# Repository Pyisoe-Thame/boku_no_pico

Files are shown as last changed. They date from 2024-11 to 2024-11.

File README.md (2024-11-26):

# Boku no Pico

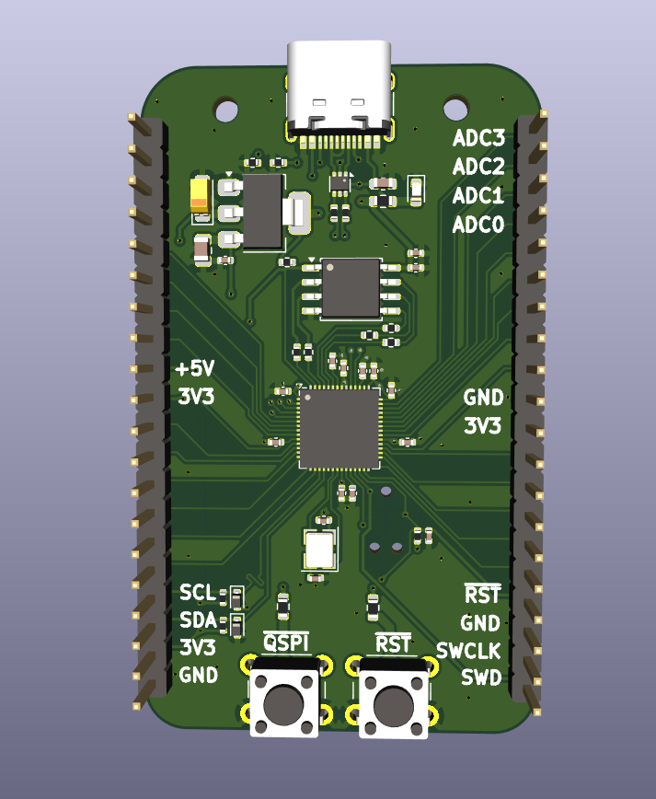
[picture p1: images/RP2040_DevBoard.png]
Front View

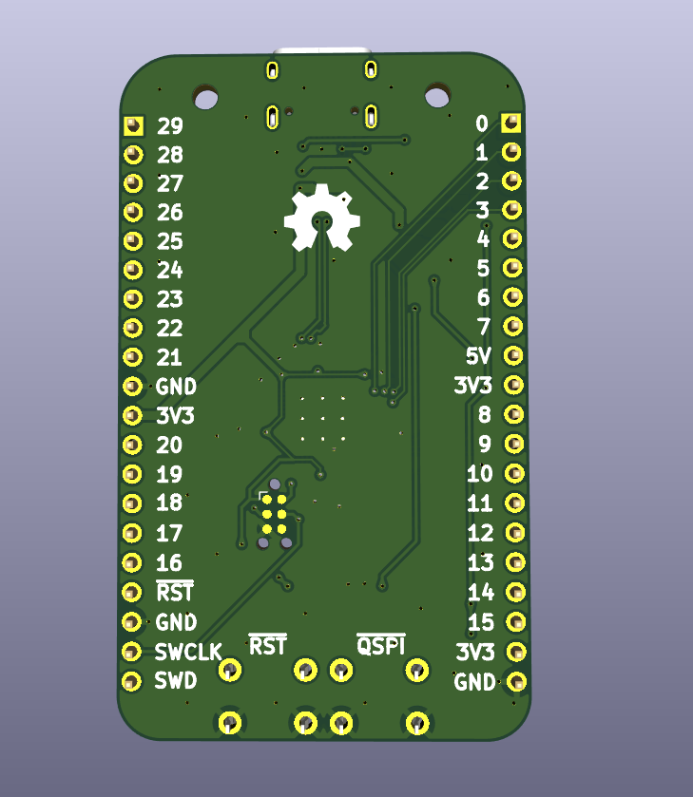
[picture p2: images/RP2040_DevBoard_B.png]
Back View
 

## Introduction
This repository contains the design files and documentation for Boku no Pico (RP2040) development board, which is a variant of ARM Cortex-M0+ Raspberry Pi Pico. This board is tailored to enhance development for embedded systems enthusiasts by adding essential features and simplifying debugging and prototyping.

---

## Features
- Powered by the Raspberry Pi RP2040 microcontroller.
- Standard 4-pin SWD and I2C headers 
- USB-C connector for modern connectivity.
- Application of robustment enhancing techniques.
- Compact, breadboard-friendly form factor.

---

## Schematic and PCB Design
The hardware design was created using **KiCad**. The following files are included:
- **Schematic**: `RP2040_DevBoard.kicad_sch`
- **PCB layout**: `RP2040_DevBoard.kicad_pcb`

### Folder Structure
- `BOM/`: Bill of Materials for the components used.
- `PCB/`: Gerber files, Drill files and PaP files.
- `images/`: Board images in 3D but no rendered.

---

## How to Use
### Hardware Setup
1. Assembly the PCB by handing the files inside BOM and PCB folders to a PCB manufacturer such as PCBHero or JLCPCB.
2. Hand-solder manually the pin headers or the way you want (e.g. sockets, wires)
3. Use a 4-pin SWD debugger (e.g., J-Link or Picoprobe) or Arm connector tag for flashing firmware.

### Programming
- Use the official Raspberry Pi Pico SDK for development.
- Alternatively, program using MicroPython or CircuitPython.

---

## Getting Started
1. Clone this repository:
   ```bash
   git clone https://github.com/Pyisoe-Thame/boku_no_pico.git

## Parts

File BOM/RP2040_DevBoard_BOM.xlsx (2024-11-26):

Designator | Label | LCSC Part # | Mfr. Part # | Manufacturer | Footprint | Quantity | Price | Stock Minimum | Cost | Actual Cost | 5 Boards Cost
C1, C4, C5, C6, C9, 10, C11, C12, C13, C15, C19 | 100nF | C392963 | TCC0402X7R104K160AT | CCTC | C_0402_1005Metric | 11 | $0.0009 | 100 | $0.0099 | $0.0900 | $0.0495
C7, C8 | 220nF | C7503518 | CGA0402X5R224K100GT | HRE | C_0402_1005Metric | 2 | 0.0014 | 100 | $0.0028 | $0.1400 | $0.0140
C2, C3 | 22pF | C2175872 | CC0402JRNPO7BN220 | YAGEO | C_0402_1005Metric | 2 | $0.0011 | 100 | $0.0022 | $0.1100 | $0.0110
C18 | 1uF | C5142580 | TCC0402X5R105K160AT | CCTC | C_0402_1005Metric | 1 | $0.0020 | 100 | $0.0020 | $0.2000 | $0.0100
C14 | 4.7uF | C6119855 | CGA0603X5R475K160JT | HRE | C_0603_1608Metric | 1 | $0.0058 | 100 | $0.0058 | $0.5800 | $0.0290
C16 | 10uF | C1713 | CL21A106KOQNNNE | Samsung Electro-Mechanics | C_0805_2012Metric | 1 | $0.0078 | 20 | $0.0078 | $0.1560 | $0.0390
C17 | 22uF | C124838 | TC212A226M010B | Sunlord | CP_EIA-3216-18_Kemet-A | 1 | $0.0928 | 5 | $0.0928 | $0.4640 | $0.4640
D1, D2 | ESD5Z3.3C | C5180227 | ESD5Z3.3C-ES | ElecSuper | D_SOD-523 | 2 | $0.0132 | 5 | $0.0264 | $0.0660 | $0.1320
D3 | Red | C965799 | XL-1608SURC-06 | XINGLIGHT | LED_0603_1608Metric | 1 | $0.0030 | 100 | $0.0030 | $0.3000 | $0.0150
J1 | USB_C_2.0 | C165948 | TYPE-C-31-M-12 | Korean Hroparts Elec | USB_C_Receptacle_HRO_TYPE-C-31-M-12 | 1 | $0.1552 | 5 | $0.1552 | $0.7760 | $0.7760
R1, R11, R14, R15 | 10k | C3017497 | SCR0402J10K | VO | R_0402_1005Metric | 2 | $0.0004 | 100 | $0.0008 | $0.0400 | $0.0040
R2, R3, R4, R5, R6, R7, R8 | 27R | C2929914 | FRC0402J270TS | FOJAN | R_0402_1005Metric | 7 | $0.0003 | 100 | $0.0021 | $0.0300 | $0.0105
R9, R10 | 5k1 | C23186 | 0603WAF5101T5E | UNI-ROYAL(Uniroyal Elec) | R_0402_1005Metric | 2 | $0.0010 | 100 | $0.0020 | $0.1000 | $0.0100
R12, R13 | 1k | C881173 | CR0603J1K00P05Z | Ever Ohms Tech | R_0603_1608Metric | 2 | $0.0013 | 100 | $0.0026 | $0.1300 | $0.0130
R16 | 220R | C22962 | 0603WAF2200T5E | UNI-ROYAL(Uniroyal Elec) | R_0603_1608Metric | 1 | $0.0010 | 100 | $0.0010 | $0.1000 | $0.0050
SW1, SW2 | SW_Push | C29781309 | SMG-01-H055A1 | SM Switch | SW_PUSH_6mm | 2 | $0.0154 | 20 | $0.0308 | $0.3080 | $0.1540
U1 | RP2040 | C2040 | RP2040 | Raspberry Pi | QFN-56-1EP_7x7mm_P0.4mm_EP4x4mm_ThermalVias | 1 | $1.0357 | 1 | $1.0357 | $1.0357 | $5.1785
U2 | USBLC6-2P6 | C19188420 | LM-USBLC6-2P6 | Leiditech | SOT-563 | 1 | $0.0516 | 5 | $0.0516 | $0.2580 | $0.2580
U3 | AMS1117-3.3 | C347222 | AMS1117-3.3 | UMW(Youtai Semiconductor Co., Ltd.) | SOT-223-3_TabPin2 | 1 | $0.0335 | 5 | $0.0335 | $0.1675 | $0.1675
U4 | W25Q16JVSS | C82317 | W25Q16JVSSIQ | Winbond Elec | SOIC-8_5.275x5.275mm_P1.27mm | 1 | $0.2263 | 5 | $0.2263 | $1.1315 | $1.1315
Y1 | ABM8-272-T3 | C20625731 | ABM8-272-T3 | Abracon LLC | Crystal_SMD_Abracon_ABM8G-4Pin_3.2x2.5mm | 1 | $0.4899 | 1 | $0.4899 | $0.4899 | $2.4495
Total |  |  |  |  |  |  |  |  | $2.1842 | $6.6726 | $10.9210
 |  | Note: pin headers excluded

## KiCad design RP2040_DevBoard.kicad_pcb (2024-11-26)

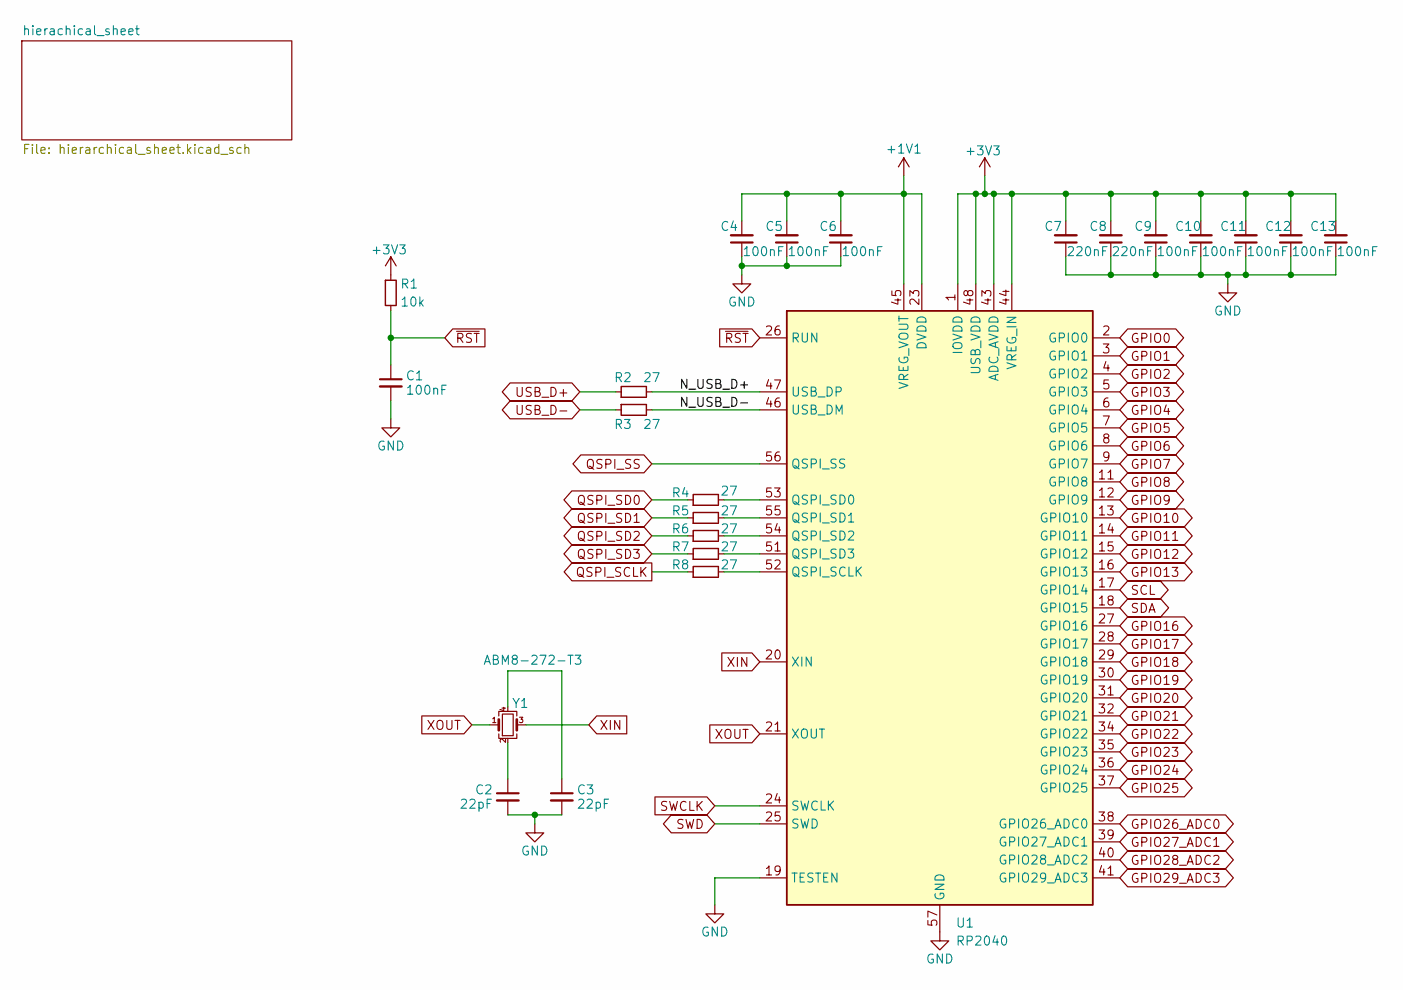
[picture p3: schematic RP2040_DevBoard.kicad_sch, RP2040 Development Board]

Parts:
C1, C4, C5, C6, C9, C10, C11, C12, C13: 100nF; C_0402_1005Metric
C2, C3: 22pF; C_0402_1005Metric
C7, C8: 220nF; C_0402_1005Metric
R1: 10k; R_0402_1005Metric
R2, R3, R4, R5, R6, R7, R8: 27; R_0402_1005Metric
U1: RP2040; QFN-56-1EP_7x7mm_P0.4mm_EP4x4mm
Y1: ABM8-272-T3; Crystal_SMD_Abracon_ABM8G-4Pin_3.2x2.5mm

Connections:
+1V1: C4.2, C5.2, C6.2, U1.23 (DVDD), U1.45 (VREG_VOUT), U1.50 (DVDD)
+3V3: C7.2, C8.2, C9.2, C10.2, C11.2, C12.2, C13.2, R1.1, U1.1 (IOVDD), U1.10 (IOVDD), U1.22 (IOVDD), U1.33 (IOVDD), U1.42 (IOVDD), U1.43 (ADC_AVDD), U1.44 (VREG_IN), U1.48 (USB_VDD), U1.49 (IOVDD); also elsewhere on the board
/N_USB_D+: R2.2, U1.47 (USB_DP)
/N_USB_D-: R3.2, U1.46 (USB_DM)
GND: C1.2, C2.2, C3.2, C4.1, C5.1, C6.1, C7.1, C8.1, C9.1, C10.1, C11.1, C12.1, C13.1, U1.19 (TESTEN), U1.57 (GND); also elsewhere on the board
GPIO0: U1.2 (GPIO0); also elsewhere on the board
GPIO1: U1.3 (GPIO1); also elsewhere on the board
GPIO2: U1.4 (GPIO2); also elsewhere on the board
GPIO3: U1.5 (GPIO3); also elsewhere on the board
GPIO4: U1.6 (GPIO4); also elsewhere on the board
GPIO5: U1.7 (GPIO5); also elsewhere on the board
GPIO6: U1.8 (GPIO6); also elsewhere on the board
GPIO7: U1.9 (GPIO7); also elsewhere on the board
GPIO8: U1.11 (GPIO8); also elsewhere on the board
GPIO9: U1.12 (GPIO9); also elsewhere on the board
GPIO10: U1.13 (GPIO10); also elsewhere on the board
GPIO11: U1.14 (GPIO11); also elsewhere on the board
GPIO12: U1.15 (GPIO12); also elsewhere on the board
GPIO13: U1.16 (GPIO13); also elsewhere on the board
GPIO16: U1.27 (GPIO16); also elsewhere on the board
GPIO17: U1.28 (GPIO17); also elsewhere on the board
GPIO18: U1.29 (GPIO18); also elsewhere on the board
GPIO19: U1.30 (GPIO19); also elsewhere on the board
GPIO20: U1.31 (GPIO20); also elsewhere on the board
GPIO21: U1.32 (GPIO21); also elsewhere on the board
GPIO22: U1.34 (GPIO22); also elsewhere on the board
GPIO23: U1.35 (GPIO23); also elsewhere on the board
GPIO24: U1.36 (GPIO24); also elsewhere on the board
GPIO25: U1.37 (GPIO25); also elsewhere on the board
GPIO26_ADC0: U1.38 (GPIO26_ADC0); also elsewhere on the board
GPIO27_ADC1: U1.39 (GPIO27_ADC1); also elsewhere on the board
GPIO28_ADC2: U1.40 (GPIO28_ADC2); also elsewhere on the board
GPIO29_ADC3: U1.41 (GPIO29_ADC3); also elsewhere on the board
unnamed: C2.1, Y1.2
unnamed: C3.1, Y1.4
unnamed: R8.2, U1.52 (QSPI_SCLK)
unnamed: R4.2, U1.53 (QSPI_SD0)
unnamed: R5.2, U1.55 (QSPI_SD1)
unnamed: R6.2, U1.54 (QSPI_SD2)
unnamed: R7.2, U1.51 (QSPI_SD3)
QSPI_SCLK: R8.1; also elsewhere on the board
QSPI_SD0: R4.1; also elsewhere on the board
QSPI_SD1: R5.1; also elsewhere on the board
QSPI_SD2: R6.1; also elsewhere on the board
QSPI_SD3: R7.1; also elsewhere on the board
QSPI_SS: U1.56 (QSPI_SS); also elsewhere on the board
SCL: U1.17 (GPIO14); also elsewhere on the board
SDA: U1.18 (GPIO15); also elsewhere on the board
SWCLK: U1.24 (SWCLK); also elsewhere on the board
SWD: U1.25 (SWD); also elsewhere on the board
USB_D+: R2.1; also elsewhere on the board
USB_D-: R3.1; also elsewhere on the board
XIN: U1.20 (XIN), Y1.3
XOUT: U1.21 (XOUT), Y1.1
~RST: C1.1, R1.2, U1.26 (RUN); also elsewhere on the board

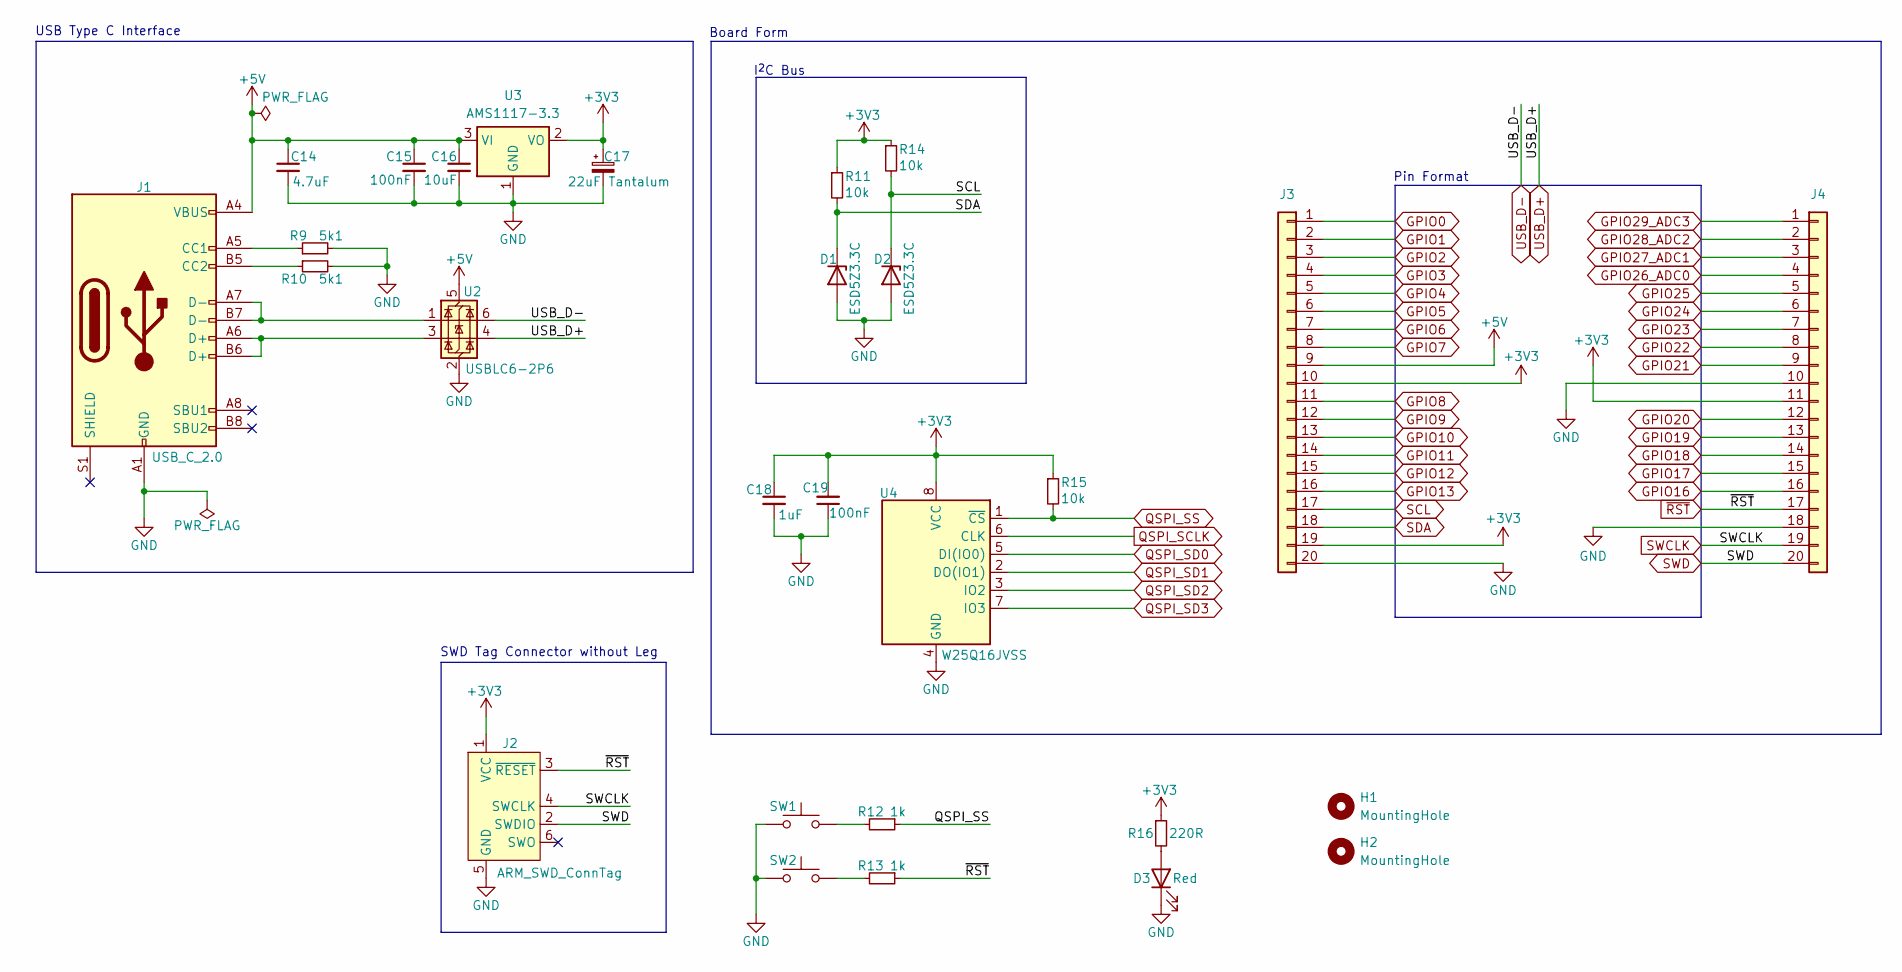
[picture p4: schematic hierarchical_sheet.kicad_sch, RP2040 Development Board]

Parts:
C14: 4.7uF; C_0603_1608Metric
C15, C19: 100nF; C_0402_1005Metric
C16: 10uF; C_0805_2012Metric
C17: 22uF; CP_EIA-3216-18_Kemet-A
C18: 1uF; C_0402_1005Metric
D1, D2: ESD5Z3.3C; D_SOD-523
D3: Red; LED_0603_1608Metric
H1, H2: MountingHole; MountingHole_2.2mm_M2
J1: USB_C_2.0; USB_C_Receptacle_HRO_TYPE-C-31-M-12
J2: ARM_SWD_ConnTag; Tag-Connect_TC2030-IDC-NL_2x03_P1.27mm_Vertical
J3, J4: Conn_01x20; PinHeader_1x20_P2.54mm_Vertical
R9, R10: 5k1; R_0402_1005Metric
R11, R14, R15: 10k; R_0402_1005Metric
R12, R13: 1k; R_0603_1608Metric
R16: 220R; R_0603_1608Metric
SW1, SW2: SW_Push; SW_PUSH_6mm
U2: USBLC6-2P6; SOT-563
U3: AMS1117-3.3; SOT-223-3_TabPin2
U4: W25Q16JVSS; SOIC-8_5.275x5.275mm_P1.27mm

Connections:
+3V3: C17.1, C18.1, C19.2, J2.1 (VCC), J3.10, J3.19, J4.11, R11.1, R14.1, R15.1, R16.1, U3.2 (VO), U4.8 (VCC); also elsewhere on the board
+5V: C14.1, C15.1, C16.1, J1.A4 (VBUS), J1.A9 (VBUS), J1.B4 (VBUS), J1.B9 (VBUS), J3.9, U2.5 (VBUS), U3.3 (VI)
GND: C14.2, C15.2, C16.2, C17.2, C18.2, C19.1, D1.2 (A), D2.2 (A), D3.1 (K), J1.A1 (GND), J1.A12 (GND), J1.B1 (GND), J1.B12 (GND), J2.5 (GND), J3.20, J4.10, J4.18, R9.2, R10.2, SW1.1, SW2.1, U2.2 (GND), U3.1 (GND), U4.4 (GND); also elsewhere on the board
GPIO0: J3.1; also elsewhere on the board
GPIO1: J3.2; also elsewhere on the board
GPIO2: J3.3; also elsewhere on the board
GPIO3: J3.4; also elsewhere on the board
GPIO4: J3.5; also elsewhere on the board
GPIO5: J3.6; also elsewhere on the board
GPIO6: J3.7; also elsewhere on the board
GPIO7: J3.8; also elsewhere on the board
GPIO8: J3.11; also elsewhere on the board
GPIO9: J3.12; also elsewhere on the board
GPIO10: J3.13; also elsewhere on the board
GPIO11: J3.14; also elsewhere on the board
GPIO12: J3.15; also elsewhere on the board
GPIO13: J3.16; also elsewhere on the board
GPIO16: J4.16; also elsewhere on the board
GPIO17: J4.15; also elsewhere on the board
GPIO18: J4.14; also elsewhere on the board
GPIO19: J4.13; also elsewhere on the board
GPIO20: J4.12; also elsewhere on the board
GPIO21: J4.9; also elsewhere on the board
GPIO22: J4.8; also elsewhere on the board
GPIO23: J4.7; also elsewhere on the board
GPIO24: J4.6; also elsewhere on the board
GPIO25: J4.5; also elsewhere on the board
GPIO26_ADC0: J4.4; also elsewhere on the board
GPIO27_ADC1: J4.3; also elsewhere on the board
GPIO28_ADC2: J4.2; also elsewhere on the board
GPIO29_ADC3: J4.1; also elsewhere on the board
unnamed: D3.2 (A), R16.2
unnamed: J1.A5 (CC1), R9.1
unnamed: J1.B5 (CC2), R10.1
unnamed: J1.A6 (D+), J1.B6 (D+), U2.3 (I/O2)
unnamed: J1.A7 (D-), J1.B7 (D-), U2.1 (I/O1)
unnamed: R12.2, SW1.2
unnamed: R13.2, SW2.2
QSPI_SCLK: U4.6 (CLK); also elsewhere on the board
QSPI_SD0: U4.5 (DI(IO0)); also elsewhere on the board
QSPI_SD1: U4.2 (DO(IO1)); also elsewhere on the board
QSPI_SD2: U4.3 (IO2); also elsewhere on the board
QSPI_SD3: U4.7 (IO3); also elsewhere on the board
QSPI_SS: R12.1, R15.2, U4.1 (~CS); also elsewhere on the board
SCL: D2.1 (K), J3.17, R14.2; also elsewhere on the board
SDA: D1.1 (K), J3.18, R11.2; also elsewhere on the board
SWCLK: J2.4 (SWCLK), J4.19; also elsewhere on the board
SWD: J2.2 (SWDIO), J4.20; also elsewhere on the board
USB_D+: U2.4 (I/O2); also elsewhere on the board
USB_D-: U2.6 (I/O1); also elsewhere on the board
~RST: J2.3 (~RESET), J4.17, R13.1; also elsewhere on the board

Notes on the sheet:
USB Type C Interface
Board Form
I^{2}C Bus
SWD Tag Connector without Leg
Pin Format

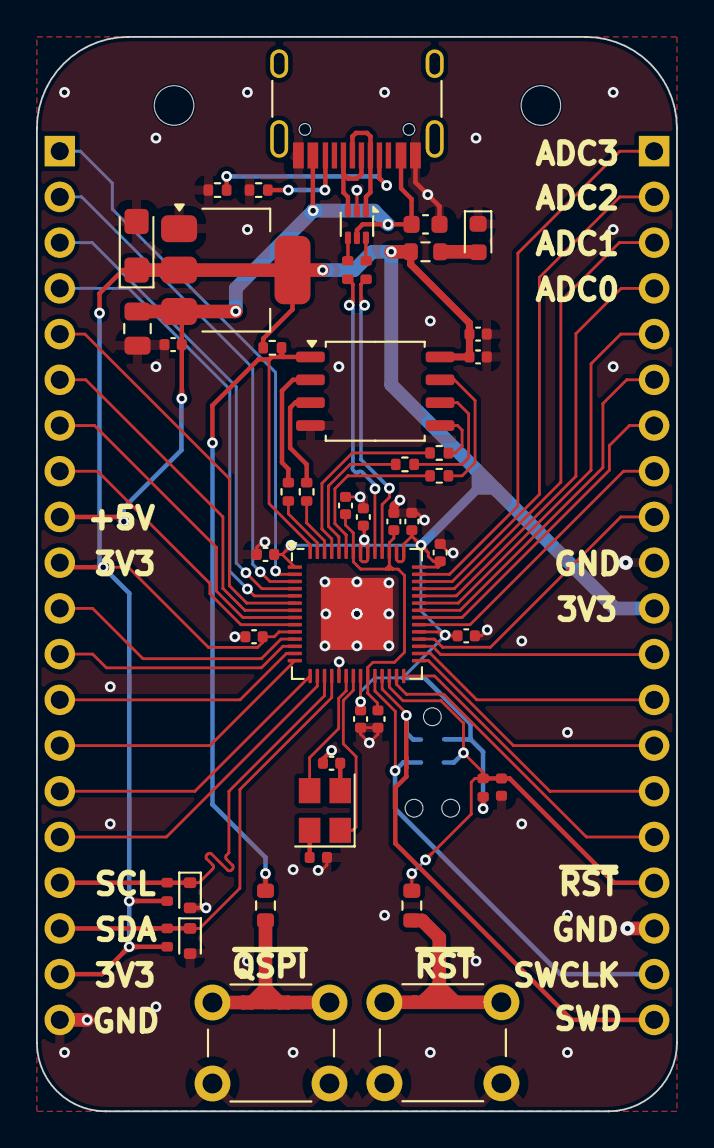
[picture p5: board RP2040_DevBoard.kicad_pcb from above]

Board: 4 copper layers, 35.6 x 59.7 mm, 51 parts (1 on the bottom side), 63 nets.
